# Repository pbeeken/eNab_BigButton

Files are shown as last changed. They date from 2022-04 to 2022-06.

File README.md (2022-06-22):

# Big Button (not too big)
This is an editable large button for use as an assistive device. While the .STL files are provided here for direct 3D printing a link is provided to [OnShape](https://www.onshape.com/en/products/free) so you can copy and scale the button to different sizes.

[Public Link to OnShape Design](https://bhhs.onshape.com/documents/78bbdee173944de41d598962/w/2f661b4d61a50f31ac1c939b/e/03b1ed92ffad79868d8ec1e2)

It is based on a [design on thingaverse](https://www.thingiverse.com/thing:3062522) downloaded a while ago by some students who wanted to customize the design. We wound up using a different switch available from [Digikey](https://www.digikey.com/en/products/detail/omron-electronics-inc-emc-div/B3F-4055/31799) which we got for $0.55. The internals of the switch was designed to fit the registration pins on the bottom of the button and to accomodate the square pin on top.  A slightly [cheaper alternative](https://www.digikey.com/en/products/detail/c-k/PTS125SJK73-2-LFS/1146902) is a button very similar but lacks the registration pins. We also closed the tolerance on the opening for the 3.1mm power cable so that screwing the top down locks the cable in place. This simplified our 'production line' manufacturing type process for [Makers Making Change](https://makersmakingchange.com/) hacked toys. 

The button is designed to be used with a standard 3.1mm audio patch cable which can be scavanged from many discarded speaker or old patch panel wires. Stereo or monorual will work.  Simply cut one end and wire the red and white leads to a switch.  The device is a favorite of a local hospital for their young members who need a larger switch for some toys we help modify.

## Modification Notes
The drawing can be expanded (to a point) by simply changing the proportions of the sketches in the x-y plane. Leave the pedistal the same size and leave the z distances the same for the same profile.  The "spiral spring" helps stabilize the z movement.

## 3D Printing Notes
So far we have printed dozens of buttons in various colors in PLA.  ABS would certainly produce a stronger more durable button but we only have 1 color in ABS.  We print the buttons in batches and then trade a different colored button (usually high contrast difference) for the button itself.  Removing the buttons are easy from a well prepared surface. We take a little extra time removing the buttons with the delicate 'spring' like spiral but if you work a spatula along the spiral to the base of the button the button usually pops off.

## Assembly Notes
We solder the jack, push the other end through the hole, solder the button and seat it onto the pedistal. Place the large button onto the small square bead and turn it until the button seats on to the square nib of the switch. Press down to hold it in place and set the ring (a little practice and you can do this very easily.)  Thread the ring onto the base and tighten while holding the button down. This will keep the button from losing the fit around the switch top. Tightening the ring will clamp the wire in place.

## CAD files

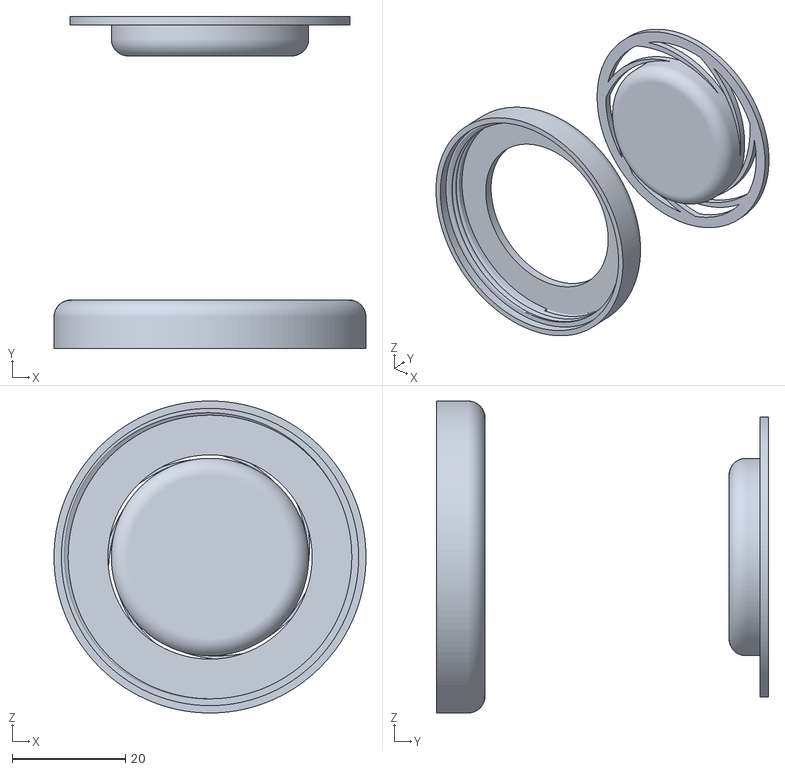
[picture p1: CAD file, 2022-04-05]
stl/AssistiveButton.stl
55.0 x 58.6 x 55.0

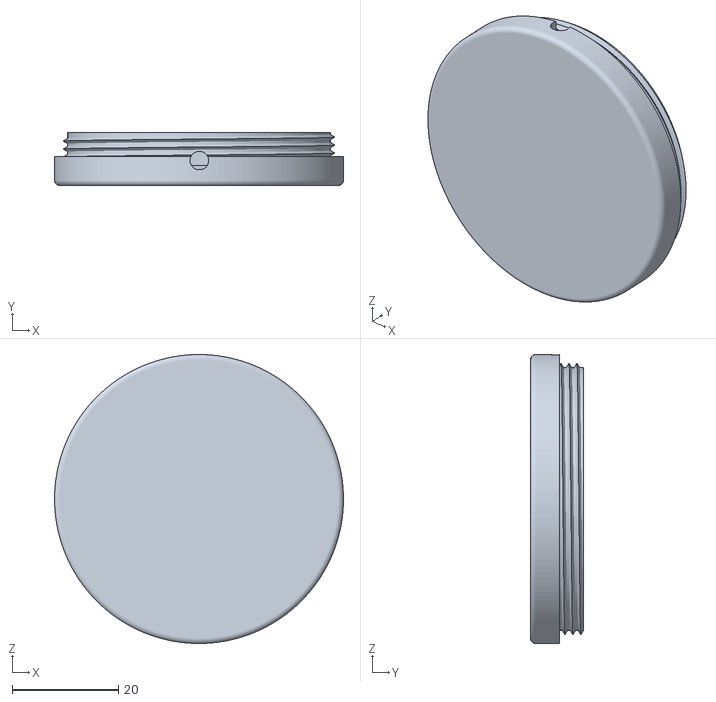
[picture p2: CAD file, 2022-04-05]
stl/AssistiveButton - Base.stl
54.4 x 10.0 x 54.4

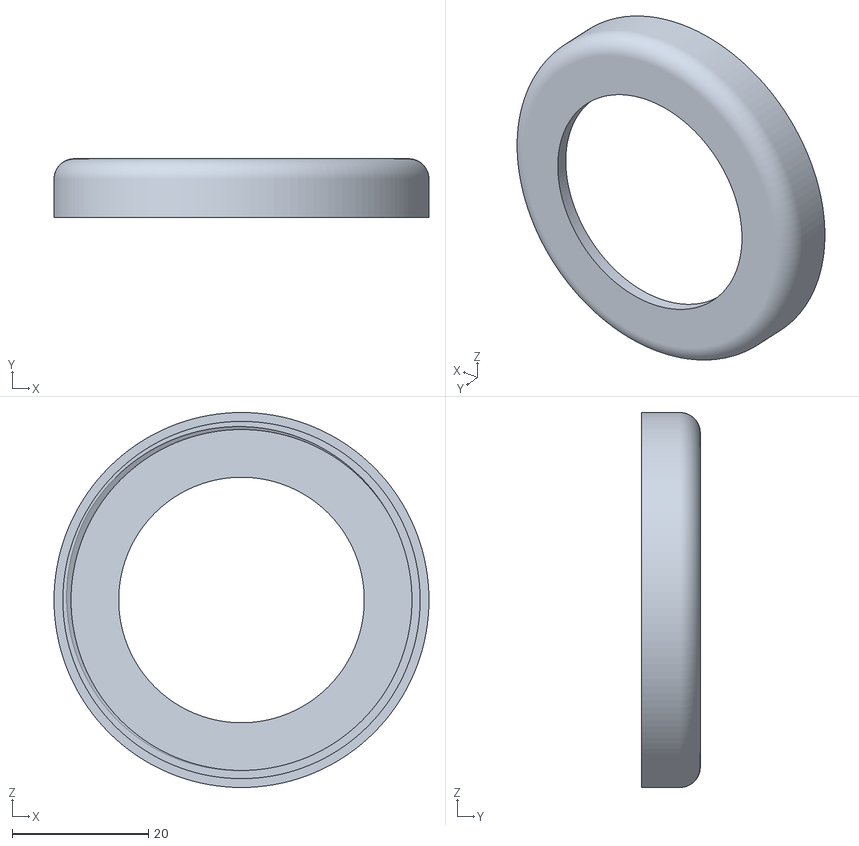
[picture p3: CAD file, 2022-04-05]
stl/AssistiveButton - Cap.stl
55.0 x 8.60 x 55.0
